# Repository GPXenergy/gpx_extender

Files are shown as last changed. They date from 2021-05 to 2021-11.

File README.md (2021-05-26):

# gpx_extender

The GPX Extender is a wireless link between the P1 port and the GPX Connector. It uses an STM32L011F4P6 and an off the shelf NRF24L01+ module to transparently transmit P1 port data. The device acts as transmitter when connected to the P1 port or as receiver when connected to the GPX Connector.

## firmware

Project files are included for Keil µVision >=v5.27.  

## hardware

The design files can be opened with Eagle v8.3.1 and up

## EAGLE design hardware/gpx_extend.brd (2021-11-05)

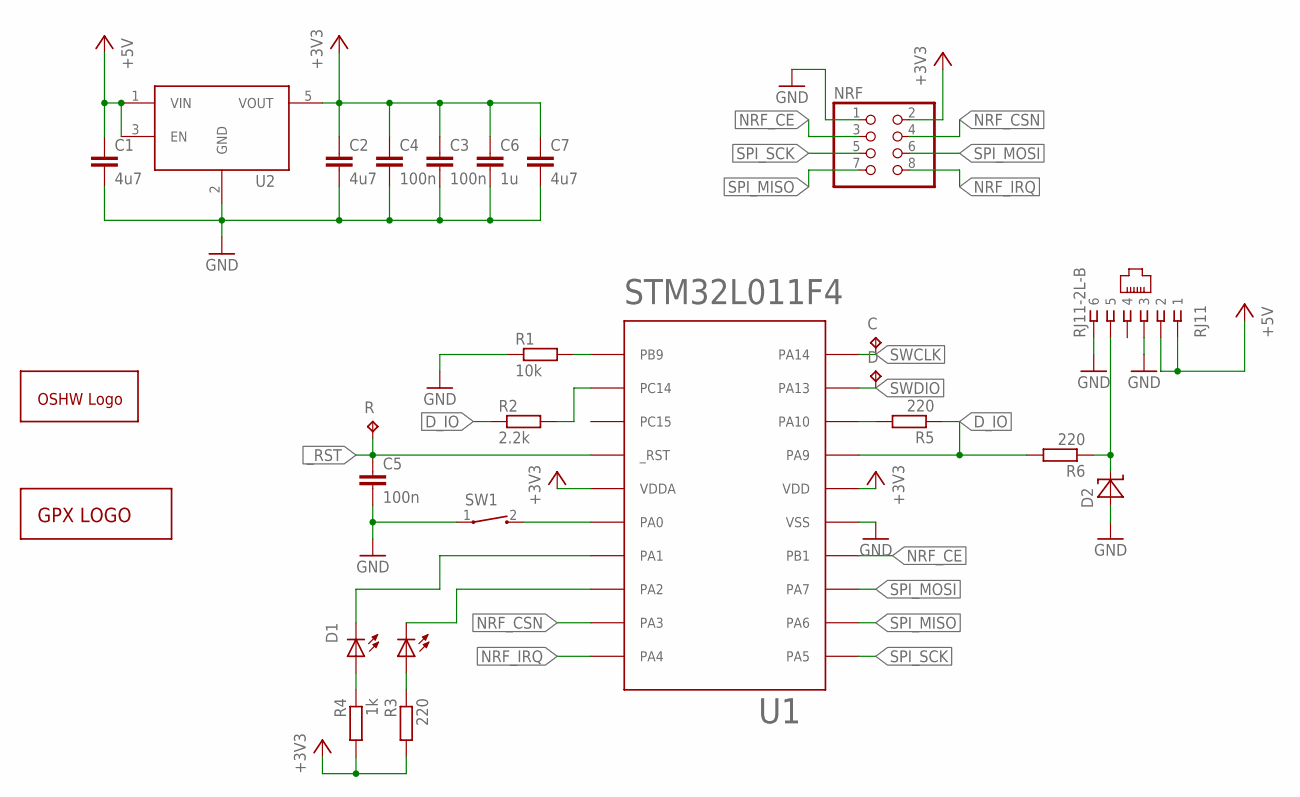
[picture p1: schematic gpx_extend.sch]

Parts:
C: TPTP10R; TP10R
C1, C2, C7: 4u7; 0603-MMGRID
C3, C4, C5: 100n; 0603-MMGRID
C6: 1u; 0603-MMGRID
D: TPTP10R; TP10R
D1: LED-DUAL; LED-1210
D2: UCLAMP3301HSOD523; SOD523
GOLD_ORB_SM1: OSHWLOGOLOGO5MM; OSHW_5MM
NRF: PINHD-2X4; 2X04
R: TPTP10R; TP10R
R1: 10k; 0603-MMGRID
R2: 2.2k; 0603-MMGRID
R3, R5, R6: 220; 0603-MMGRID
R4: 1k; 0603-MMGRID
RJ11: RJ11-2L-B; RJ11-NO_SHIELD
SW1: SW-SPST; TL3330
U1: STM32L011F4PX; TSSOP-20
U2: MIC550X; SOT23-5
U$1: GPX_LOGO

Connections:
+3V3: C2.1, C3.1, C4.1, C6.1, C7.1, NRF.2, R3.2, R4.2, U1.P$5 (VDDA), U1.P$16 (VDD), U2.5 (VOUT)
+5V: C1.1, RJ11.1, RJ11.2, U2.1 (VIN), U2.3 (EN)
BOOT0: R1.2, U1.P$1 (PB9)
BTN: SW1.2, U1.P$6 (PA0)
D_IO: R2.1, R5.1, R6.2, U1.P$17 (PA9)
GND: C1.2, C2.2, C3.2, C4.2, C5.2, C6.2, C7.2, D2.A, NRF.1, R1.1, RJ11.3, RJ11.6, SW1.1, U1.P$15 (VSS), U2.2 (GND)
unnamed: D2.C, R6.1, RJ11.5
unnamed: D1.1 (C0), U1.P$8 (PA2)
unnamed: D1.3 (C1), U1.P$7 (PA1)
unnamed: D1.2 (A0), R3.1
unnamed: D1.4 (A1), R4.1
NRF_CE: NRF.3, U1.P$14 (PB1)
NRF_CSN: NRF.4, U1.P$9 (PA3)
NRF_IRQ: NRF.8, U1.P$10 (PA4)
PC14: R2.2, U1.P$2 (PC14)
RX: R5.2, U1.P$18 (PA10)
SPI_MISO: NRF.7, U1.P$12 (PA6)
SPI_MOSI: NRF.6, U1.P$13 (PA7)
SPI_SCK: NRF.5, U1.P$11 (PA5)
SWCLK: C.TP, U1.P$20 (PA14)
SWDIO: D.TP, U1.P$19 (PA13)
_RST: C5.1, R.TP, U1.P$4 (_RST)

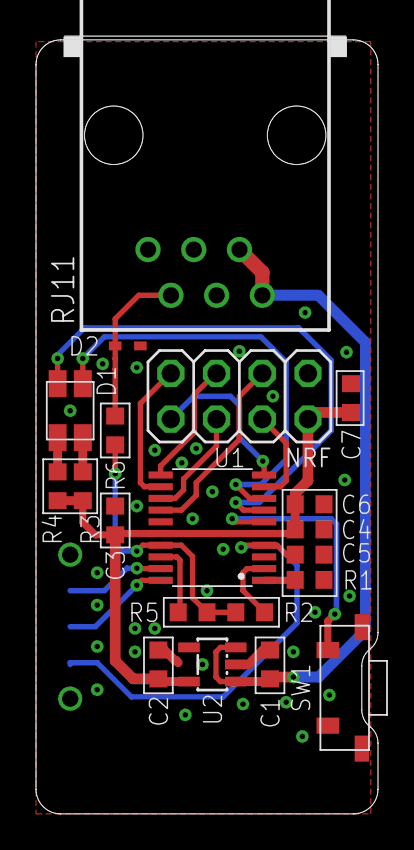
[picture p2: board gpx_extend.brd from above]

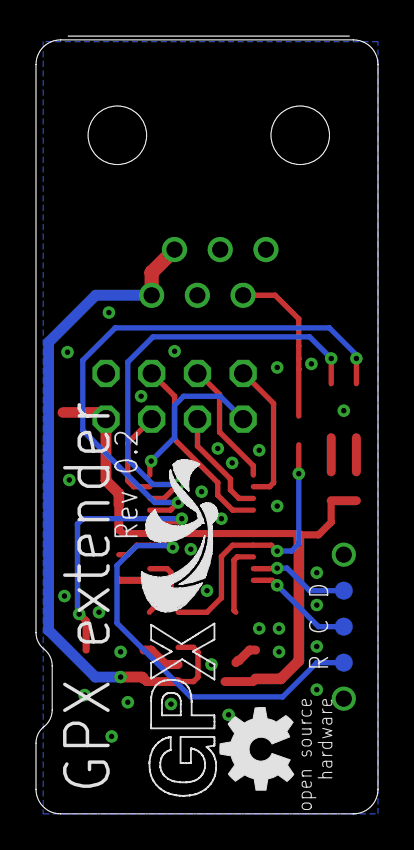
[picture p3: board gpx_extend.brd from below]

Board: 2 copper layers, 19.0 x 43.0 mm, 25 parts (5 on the bottom side), 22 nets.

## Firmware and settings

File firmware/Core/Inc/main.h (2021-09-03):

#ifndef __MAIN_H
#define __MAIN_H


#include "stm32l0xx_hal.h"

typedef enum{
    NRF_SUCCESS,
    NRF_FAIL,
    NRF_TIMEOUT,
    NRF_NORESPONSE
} nrf_status;

typedef enum{
    ANNOUNCE            = 0xAE,
    ANNOUNCE_RESPONSE   = 0xAC,
    DATA_PKT            = 0xDA,
    PAIR_TX             = 0x7E,
    PAIR_RX             = 0xCE,
    KEEPALIVE_PKT       = 0xF5
} nrf_packet_type;

typedef enum{
    UNINITIALISED,
    METER_SIDE,
    GPX_SIDE
} connection_side;


// additional NRF pins
#define CS_PORT             GPIOA
#define CS_PIN              GPIO_PIN_3
#define CE_PORT             GPIOB
#define CE_PIN              GPIO_PIN_1
#define IRQ_PORT            GPIOA
#define IRQ_PIN             GPIO_PIN_4
// gpio pins
#define LED1_PORT           GPIOA
#define LED1_PIN            GPIO_PIN_1
#define LED2_PORT           GPIOA
#define LED2_PIN            GPIO_PIN_2
#define BTN_PORT            GPIOA
#define BTN_PIN             GPIO_PIN_0
#define PULLUP_PIN          GPIO_PIN_14
#define PULLUP_PORT         GPIOC

#define RAW_PACKET_SIZE     32
#define PACKET_DATA_SIZE    30

#define PUTCHAR_PROTOTYPE int fputc(int ch, FILE *f)


void user_init(void);
void gpio_init(void);

void red_led_on(void);
void red_led_off(void);
void green_led_on(void);
void green_led_off(void);
void user_CE_hi(void);
void user_CE_low(void);
void user_CS_hi(void);
void user_CS_low(void);


void Error_Handler(void);


#endif // __MAIN_H 

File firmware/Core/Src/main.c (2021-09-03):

/* 
    GPX extender prototype based on STM32L011F4
        - detects connection to either GPX connector or P1 port
        - transmits P1 port data to paired extender via NRF24L01+ module
    
    Pin configuration:

    PA0     ------> BTN
    PA1     ------> LED1 (red)
    PA2     ------> LED2 (green)
    PA3     ------> CS
    PA4     ------> IRQ
    PA5     ------> SPI1_SCK
    PA6     ------> SPI1_MISO
    PA7     ------> SPI1_MOSI 
    PB1     ------> CE
    PA9     ------> UART2_TX, inverted, pullup enabled (if connected to gpxconn, else gpio input with pullup)
    PA10    ------> UART2_RX, OD, inverted (if connected to P1 port, else analog input)
    PA13    ------> SWDIO
    PA14    ------> SWCLK
    PC15    ------> driven high to function as strong pullup if connected to P1 port (2K ohms to UART2_RX)

    peripheral overview:
    
    Systick
        used for LED blinking and keepalive timeout
    LPTIM1
        used for long button press timing, IRQ every 10ms
    TIM2
        1µs clock, IRQ on update, used for delay_us and delay_ms
    TIM12
        1µs clock, IRQ on update, used for call_after_us 
    UART2
        baudrate and stop/databits set in extender_config.h 
        only one direction is initialised, RX interrupt based, TX uses DMA channel 4
    SPI
        8MHz full duplex master, for communication with NRF24L01
    
    TODO:   
        replace remaining HAL usage:
            SystemClock_Config
            LPM functions and macros
            GPIO_init
            RCC macros
*/

#include <stdint.h>
#include <string.h>
#include <stdio.h>
#include "main.h"
#include "extender_config.h"
#include "uart.h"
#include "spi.h"
#include "timing.h"
#include "gpxtend_nrf.h"
#include "crc.h"
#include "gpio.h"

void SystemClock_Config(void);

void EXTI0_1_IRQHandler(void);
void EXTI4_15_IRQHandler(void);
void TIM2_IRQHandler(void);
void TIM21_IRQHandler(void);
void LPTIM1_IRQHandler(void);
void SysTick_Handler(void);

// static functions
static void unpaired_loop(void);
static nrf_status pair_loop(void);
static void tx_loop(uint8_t *addr);
static void rx_loop(uint8_t *addr);
static void get_device_uid(uint32_t * uid);
static void set_device_addr(uint32_t * uid);
static void write_opposite_addr(uint8_t *addr);
static uint8_t read_opposite_addr(uint8_t *addr);
static connection_side detect_conn_side(void);

static void blink(led_colour_t colour, uint_fast16_t duration);
static void pair_success_blink(void);

// globals
void (*delayed_callback)(void);
uint8_t device_addr[5] __attribute__((aligned (2))) = {0};
volatile uint_fast8_t nrf_irq_flag = 0, tim2_flag = 0, btn_timer_active = 0;
static volatile uint_fast8_t pair_btn = 0;
static volatile uint_fast16_t red_ontime = 0, green_ontime = 0, ms_since_last_tx = 0, pressed_time = 0, released_time = 0;
connection_side side = UNINITIALISED;
gpxtendo_uart_data uart2 = {0};

int main(void)
{
    uint8_t opposite_addr[ADDR_WIDTH] = {0};
    uint_fast8_t saved_addr_valid = 0;
    uint32_t chip_uid[4] = {0};
    
    HAL_Init();
    SystemClock_Config();
    
    gpio_init();
    tim21_init();
    tim2_init();
    lptim1_init();
    spi1_init();
    crc_init();  
    
    
    side = detect_conn_side();
    get_device_uid(chip_uid);
    set_device_addr(chip_uid);
    saved_addr_valid = read_opposite_addr(opposite_addr);
    
    if(side == GPX_SIDE){   // only initialise UART for tx when connected to GPX
        uart2_init_txonly_dma();
        
        #ifdef DEBUGPRINT
        uart2_putstr_dma("\nGPX extender prototype v" VERSION_STR "\n");
        uart2_putstr_dma("built on " __DATE__ " " __TIME__ "\n");
        printf("chip UID: %08x %08x %08x\n", chip_uid[0], chip_uid[1], chip_uid[2]);
        printf("device address: %02x %02x %02x %02x %02x (crc=%02x)\n", device_addr[0], device_addr[1], device_addr[2], device_addr[3], device_addr[4], calc_crc(device_addr, ADDR_WIDTH));
        printf("paired address: %02x %02x %02x %02x %02x\n\n", opposite_addr[0], opposite_addr[1], opposite_addr[2], opposite_addr[3], opposite_addr[4]);
        
        uart2_putstr_dma("radio rx --> serial tx\n");
        #endif //DEBUGPRINT
    }
    
    // NRF24L01 startup delay
    delay_ms(80);   
    if(saved_addr_valid){
        nrf_init(device_addr, opposite_addr);
    }
    else{
        nrf_init(device_addr, ANNOUNCE_ADDR);
    }
    
    
    while(1){
        if(!saved_addr_valid){
            unpaired_loop();
        }
        else{
            if(side == METER_SIDE){
                tx_loop(opposite_addr);
            }
            else{
                rx_loop(opposite_addr);
            }
        }
        if(pair_btn){
            pair_btn = 0;
            if(pair_loop() == NRF_SUCCESS){
                saved_addr_valid = read_opposite_addr(opposite_addr);
            }
        }
    }
    
}

static void get_device_uid(uint32_t * uid)
{
    uid[0] = *((uint32_t *)UID_BASE);
    uid[1] = *((uint32_t *)(UID_BASE + 0x04U));
    uid[2] = *((uint32_t *)(UID_BASE + 0x14U));
}

static void set_device_addr(uint32_t * uid)
{
    device_addr[0] = uid[0] >> 24;      // first byte of address is wafer number 
    
    uint32_t temp = __REV(uid[2]);      // reverse byte order of unique ID bits
    memcpy(&device_addr[1], &temp, 4);  
}

static connection_side detect_conn_side()
{
    // PA9      ------> USART2_TX
    // PA10     ------> USART2_RX
    
    // set both pins to input with pulldown on PA9
    GPIOA->PUPDR &= ~(GPIO_PUPDR_PUPD9 | GPIO_PUPDR_PUPD10);
    GPIOA->PUPDR |= GPIO_PUPDR_PUPD9_1;
    GPIOA->MODER &= ~(GPIO_MODER_MODE9 | GPIO_MODER_MODE10);
    
    delay_ms(1);   // don't read directly after changing pin setting
    
    if(gpio_read(GPIOA, GPIO_PIN_10)){
        return GPX_SIDE;    // external pullup present means we're connected to the GPX connector
    }
    else{
        return METER_SIDE;  
    }
}

// idle loop with blinking to indicate unpaired state
static void unpaired_loop(void)
{
    red_led_off();
    green_led_off();
    
    while(!pair_btn){
        blink(UNPAIRED_BLINK_COLOUR, UNPAIRED_BLINK_ONTIME);
        delay_ms(UNPAIRED_BLINK_OFFTIME);
    }
    red_ontime = 0;
    red_led_off();
}
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

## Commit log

2021-03-11 add original keil and eagle projects
    [gpxtendo.brd, gpxtendo.sch, gpxtendo_rev2.brd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]
2021-03-11 add bom.txt
2021-03-11 add bill of materials
2021-05-26 add design files for rev2 board
    [gpx_extend.brd, gpx_extend.sch]
2021-07-14 fix pin config for new hardware and reduce txpower for <100mA operation
    [gpxtend_nrf.c, main.c, main.h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]
2021-09-03 consolidate config into extender_config.h, add support for uart parity and stopbits
2021-11-05 fix DMA transfer bug at lower baudrates
    [gpx_extend.brd, gpx_extend.sch]
